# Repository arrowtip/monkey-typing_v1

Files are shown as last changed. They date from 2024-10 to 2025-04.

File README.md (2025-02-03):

# monkey_typing V1
<p align="center">
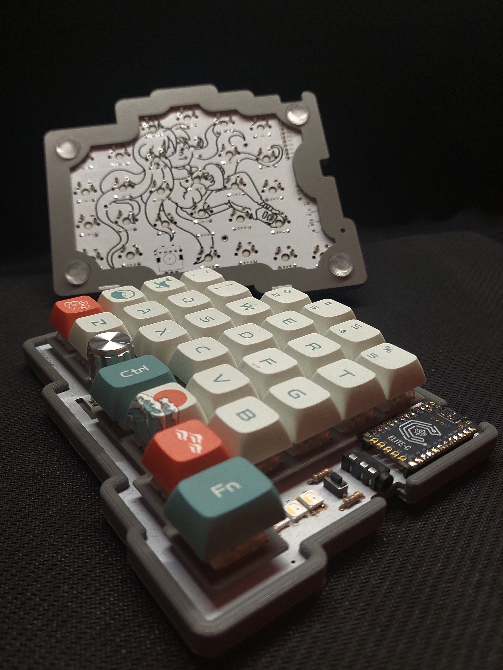
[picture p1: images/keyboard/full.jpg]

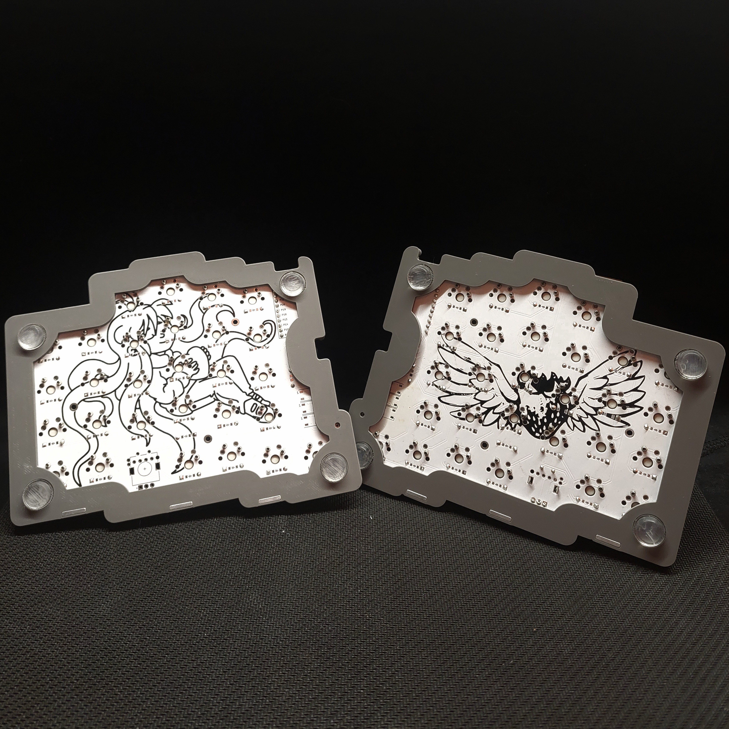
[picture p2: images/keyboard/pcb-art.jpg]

</p>

## Setup
Install ergogen cli:
```bash
$ npm i ergogen
```

## Usage
To compile the ergogen config into an (unrouted) KiCad PCB run
```bash
$ cd ergogen/
$ make
```
This will create a KiCad PCB under `ergogen/output/pcbs/monkey-typing_v1.kicad_pcb`.
Then copy this file to another location for routing.
Prerouted versions of the keyboard can be found in `kicad/`.

## Build
### Parts
- [3D-printable case](https://cad.onshape.com/documents/ed0d6a4fe642353b2203faf0/w/5ff3ead430589bfdb49bdc3b/e/f0c0ddc8bc3d8364728c5712)
- [3D-printable switch plate](https://cad.onshape.com/documents/5edfe701ad9f2b4f2a2a6781/w/f609051c12ccf6833f78234f/e/c55f49f04b746962ac1a3068)
- 58 diodes (e.g. 1N48)
- 56 mx-style switches
- mx-style keycaps
- rotary encoder (e.g. KY-040)
- 2 through-hole reset buttons
- 2 TRRS jacks TRRS-PJ-320A
- TRRS cable
- 4 6.8 kOhm resistors
- 6 WS2812B or SK6812 LEDs
- 2 microcontrollers (pro-micro or elite-c)

### Assembly
The RGB diodes are hard to hand solder, so using reflow soldering here is 
recommended.

Add two small drops of solder to the three-way jumpers below the microcontroller
on each side to connect the i2c SDA line/GND from the TRRS jack to the 
microcontroller.

Snapping the PCB into the 3D printed case might require a bit of force.
Solder all components before inserting the PCB into the case,
as removing the PCB again from the case might be difficult.

> [!CAUTION]
> Never plug the TRRS cable in or out while the keyboard is connected via USB!

### Firmware
Flash the [QMK firmware](https://github.com/arrowtip/monkey-typing_qmk) to the microcontrollers on both sides.

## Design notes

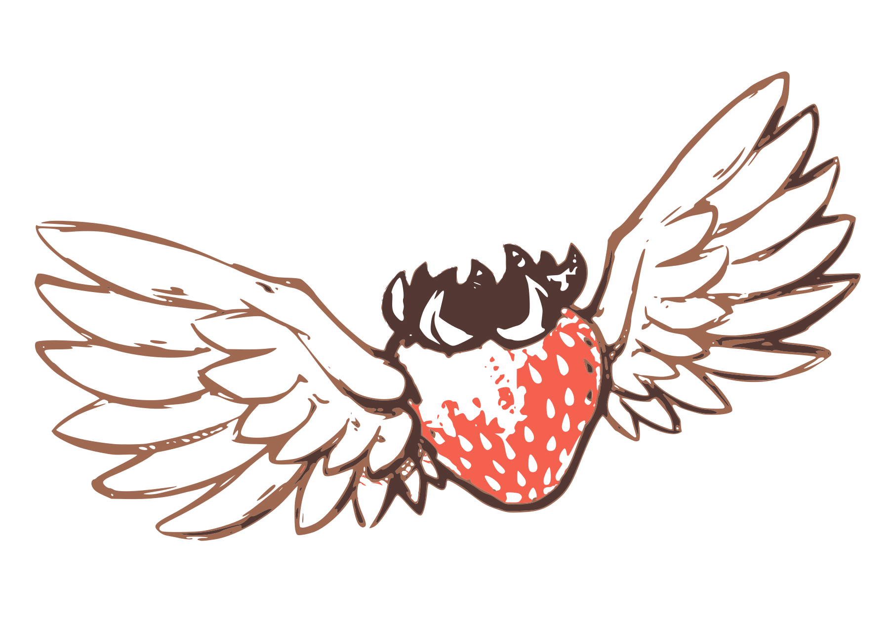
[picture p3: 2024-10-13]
images/celeste/winged-berry_reduced.png

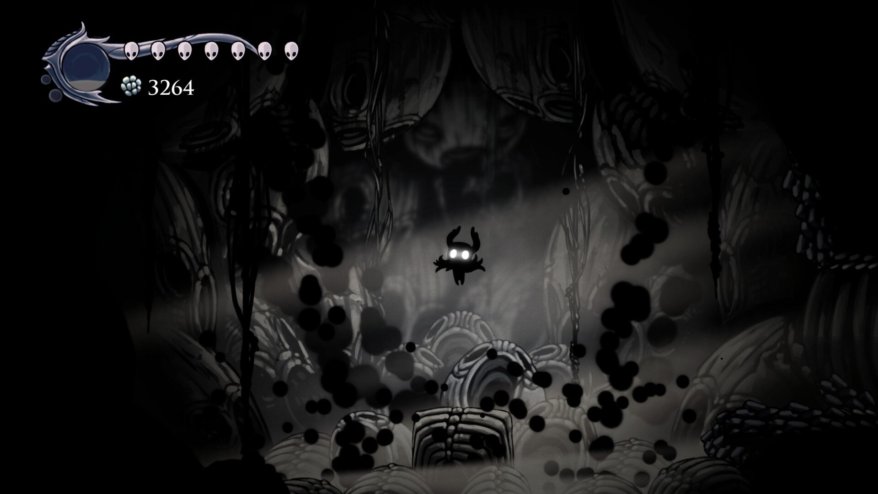
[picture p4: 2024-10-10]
images/hollow-knight/hollow-knight_shadow.jpeg

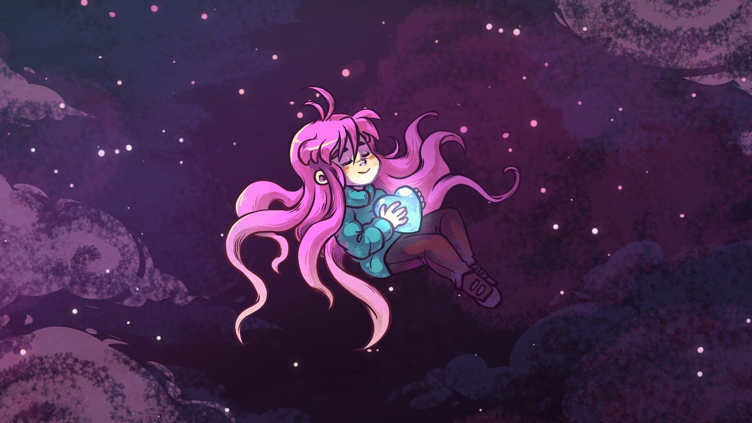
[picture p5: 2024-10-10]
images/celeste/celeste_crystal-heart_orig.jpeg

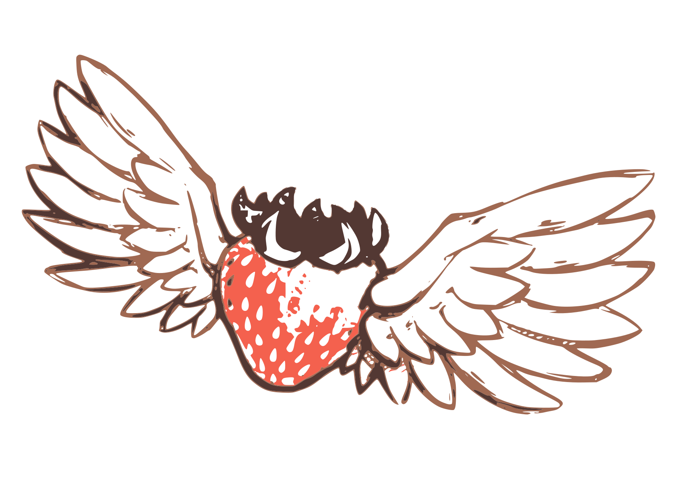
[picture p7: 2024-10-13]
images/celeste/winged-berry_reduced_mirrored.png

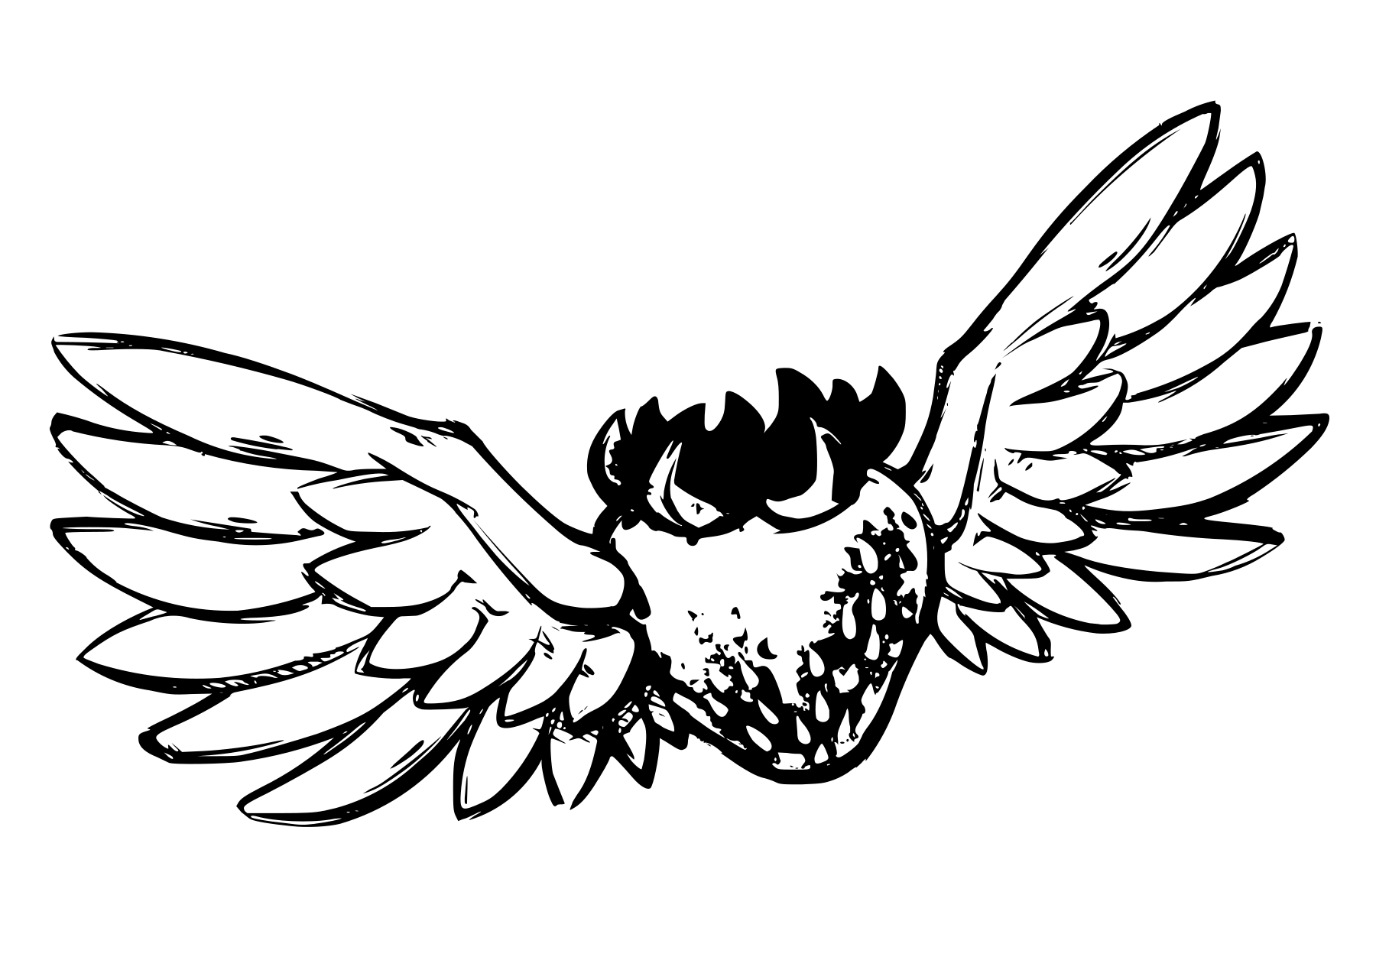
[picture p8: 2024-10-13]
images/celeste/winged-berry_01_optimized.png

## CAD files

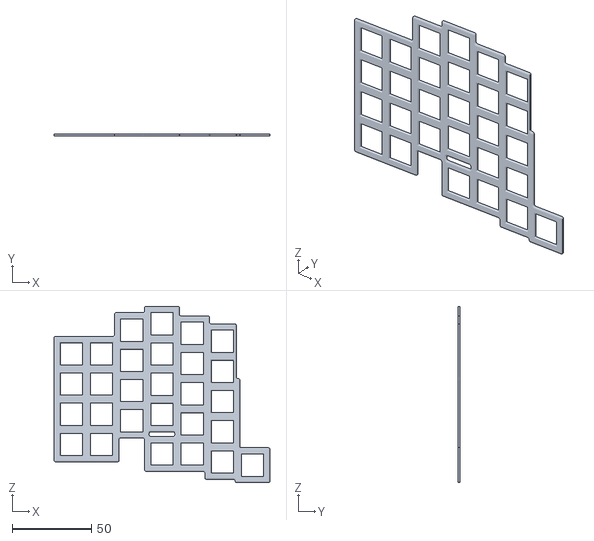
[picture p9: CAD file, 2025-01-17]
parts/switch-plate_v1.stl
136.3 x 1.50 x 111.2

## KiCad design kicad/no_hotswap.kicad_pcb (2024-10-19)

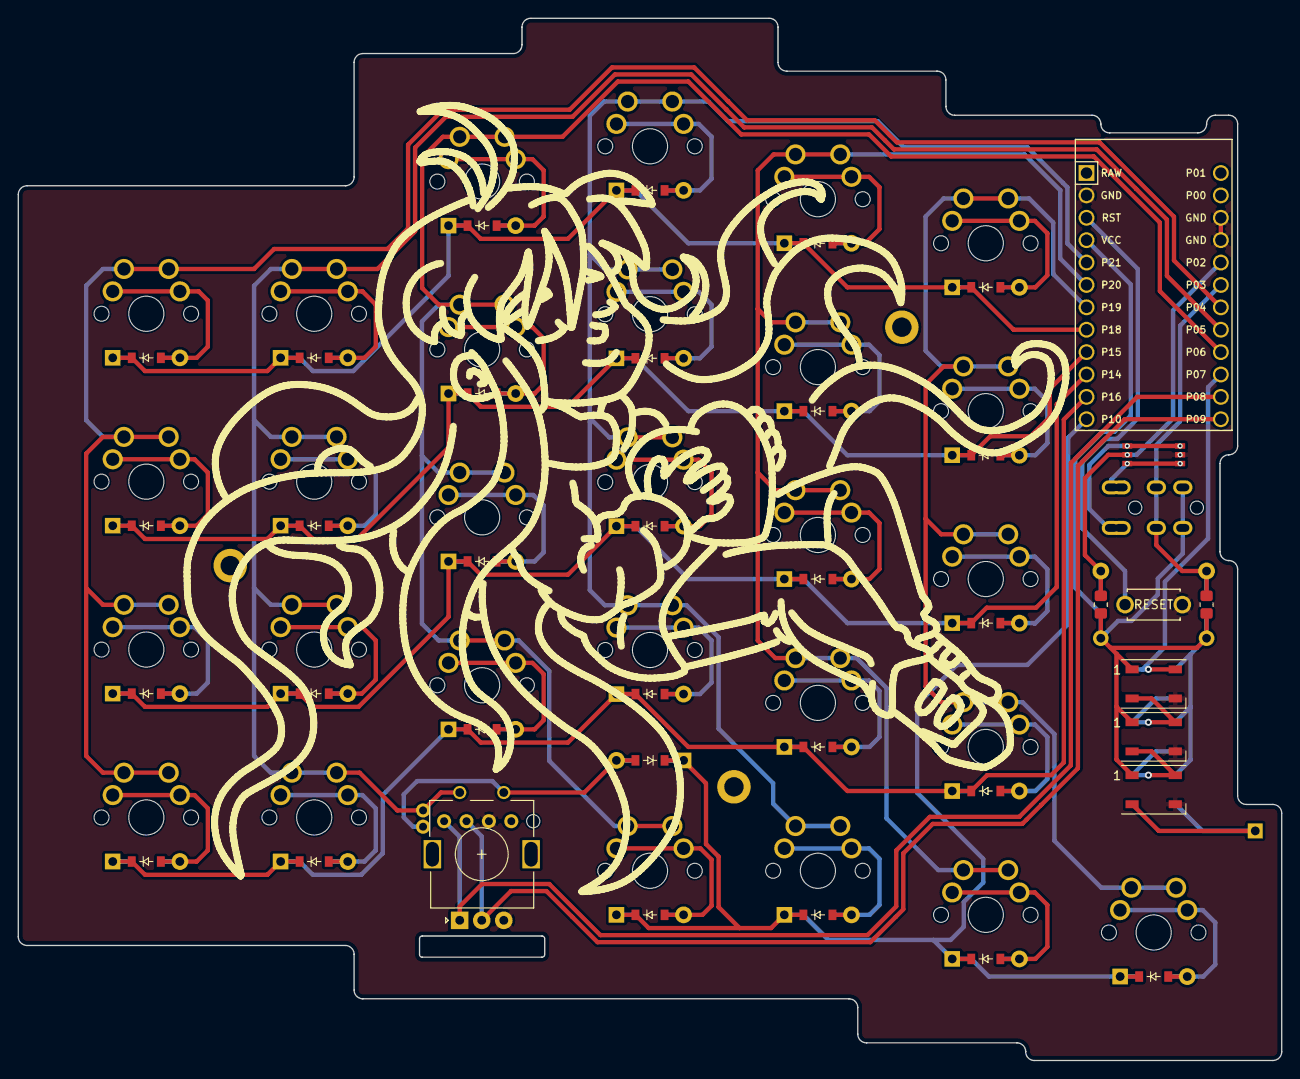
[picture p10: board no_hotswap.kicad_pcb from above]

Board: 2 copper layers, 143.3 x 118.2 mm, 68 parts (0 on the bottom side), 49 nets.

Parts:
D1, D2, D3, D4, D5, D6, D7, D8, D9, D10, D11, D12, D13, D14, D15, D16, D17, D18, D19, D20, D21, D22, D23, D24, D25, D26, D27, D28, D29: ComboDiode
Ju31, Ju32: Jumper; threeway_jumper
MCU1: ProMicro
R1, R2: ComboResistor
ROT1: rotary_encoder
S1, S2, S3, S4, S5, S6, S7, S8, S9, S10, S11, S12, S13, S14, S15, S16, S17, S18, S19, S20, S21, S22, S23, S24, S25, S26, S27, S28: MX
TRRS1: TRRS-PJ-320A-dual
_1: ResetSW
_2, _3, _4: MountingHole_2.2mm_M2

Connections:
GND: Ju32.2, Ju32.5, MCU1.2, MCU1.15, MCU1.16, ROT1.B, _1.2
P2: Ju31.2, Ju31.5, MCU1.17, R1.2
P3: MCU1.18, R2.2, TRRS1.3
P4: MCU1.19, S1.1, S2.1, S3.1, S4.1
P5: MCU1.20, ROT1.1, S5.1, S6.1, S7.1, S8.1
P6: MCU1.21, S9.1, S10.1, S11.1, S12.1, S25.1
P8: MCU1.23, ROT1.A
P9: MCU1.24, ROT1.C
P10: D25.1, D26.1, D27.1, D28.1, D29.1, MCU1.12
P14: D2.1, D6.1, D10.1, D14.1, D18.1, D22.1, MCU1.10
P15: D3.1, D7.1, D11.1, D15.1, D19.1, D23.1, MCU1.9
P16: D1.1, D5.1, D9.1, D13.1, D17.1, D21.1, MCU1.11
P18: D4.1, D8.1, D12.1, D16.1, D20.1, D24.1, MCU1.8
P19: MCU1.7, S21.1, S22.1, S23.1, S24.1, S28.1
P20: MCU1.6, S17.1, S18.1, S19.1, S20.1, S27.1
P21: MCU1.5, S13.1, S14.1, S15.1, S16.1, S26.1
RST: MCU1.3, _1.1
VCC: MCU1.4, R1.1, R2.1, TRRS1.4
far_thumb: D27.2, S27.2
farfar_thumb: D28.2, S28.2
home_thumb: D26.2, S26.2
index_bottom: D17.2, S17.2
index_home: D18.2, S18.2
index_num: D20.2, S20.2
index_top: D19.2, S19.2
inner_bottom: D21.2, S21.2
inner_home: D22.2, S22.2
inner_num: D24.2, S24.2
inner_top: D23.2, S23.2
middle_bottom: D13.2, S13.2
middle_home: D14.2, S14.2
middle_num: D16.2, S16.2
middle_top: D15.2, S15.2
my_col_row: D29.2, ROT1.2
near_thumb: D25.2, S25.2
outer_bottom: D1.2, S1.2
outer_home: D2.2, S2.2
outer_num: D4.2, S4.2
outer_top: D3.2, S3.2
pinky_bottom: D5.2, S5.2
pinky_home: D6.2, S6.2
pinky_num: D8.2, S8.2
pinky_top: D7.2, S7.2
ring_bottom: D9.2, S9.2
ring_home: D10.2, S10.2
ring_num: D12.2, S12.2
ring_top: D11.2, S11.2
trrs_gnd: Ju31.3, Ju31.6, Ju32.3, Ju32.6, TRRS1.1
trrs_sda: Ju31.1, Ju31.4, Ju32.1, Ju32.4, TRRS1.2

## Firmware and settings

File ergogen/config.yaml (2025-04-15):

meta:
  engine: 4.1.0
  author: Jakob Schmid
  version: v1.1
units:
  U: 19.05 # 19.05mm MX spacing
  u: 19 # 19mm MX spacing
  cx: 18 # 18mm Choc X spacing
  cy: 17 # 17mm Choc Y spacing
  px: U/2+5
  py: U/2+5
  switch_x: 14 # width of switch cutout
  switch_y: 14
  plate_x: 22 # width of switch plate around switches
  plate_y: 22
  stagger_ring: 15
  stagger_middle: 4
  stagger_index: -6
  stagger_inner: -5
  stagger_farfar: -2
  trrs_y_shift: -30
  reset_y_shift: -41
  trrs_jumper_y_shift: trrs_y_shift+6
points:
  key.spread: U
  key.padding: U
  zones:
    matrix_left:
      anchor:
        rotate: 0
        shift: [100, -150]
      columns:
        outer:
          key.col_net: D4
        pinky:
          key.col_net: C6
        ring:
          key:
            stagger: stagger_ring
            col_net: D7
        middle:
          key:
            stagger: stagger_middle
            col_net: F4
        index:
          key:
            stagger: stagger_index
            col_net: F5
        inner:
          key:
            stagger: stagger_inner
            col_net: F6
      rows:
        bottom:
          row_net: B2
        home:
          row_net: B3
        top:
          row_net: B1
        num:
          row_net: F7
    thumbfan:
      anchor:
        ref: matrix_left_middle_bottom
        shift: [0, stagger_index-U]
      columns:
        near:
          key.col_net: D7
        home:
          key.col_net: F4
        far:
          key:
            stagger: stagger_inner
            col_net: F5
        farfar:
          key:
            stagger: stagger_farfar
            col_net: F6
      rows:
        thumb:
          row_net: B6
outlines:
  board:
    - what: polygon
      operation: stack
      points:
        - ref: matrix_left_outer_num
          shift: [-px, py]
        - ref: matrix_left_pinky_num
          shift: [U-px, py]
        - ref: matrix_left_ring_num
          shift: [-px, py]
        - ref: matrix_left_ring_num
          shift: [U-px, py]
        - ref: matrix_left_middle_num
          shift: [-px, py]
        - ref: matrix_left_middle_num
          shift: [px, py]
        - ref: matrix_left_index_num
          shift: [px-U, py]
        - ref: matrix_left_index_num
          shift: [px, py]
        - ref: matrix_left_inner_num
          shift: [px-U, py]
          # usb-c indent
        - ref: matrix_left_inner_num
          shift: [U-6, py]
        - ref: matrix_left_inner_num
          shift: [U-6, py-2]
        - ref: matrix_left_inner_num
          shift: [U+6, py-2]
        - ref: matrix_left_inner_num
          shift: [U+6, py]

        - ref: matrix_left_inner_num
          shift: [1.5U, py]
          # trrs indent
        - ref: matrix_left_inner_num
          shift: [1.5U, trrs_y_shift+6]
        - ref: matrix_left_inner_num
          shift: [1.5U-2, trrs_y_shift+6]
        - ref: matrix_left_inner_num
          shift: [1.5U-2, trrs_y_shift-6]
        - ref: matrix_left_inner_num
          shift: [1.5U, trrs_y_shift-6]

        - ref: thumbfan_farfar_thumb
          shift: [0.5U, py]
        - ref: thumbfan_farfar_thumb
          shift: [px, py]
        - ref: thumbfan_farfar_thumb
          shift: [px, -py]
        - ref: thumbfan_farfar_thumb
          shift: [-px, -py]
        - ref: thumbfan_far_thumb
          shift: [U-px, -py]
        - ref: thumbfan_far_thumb
          shift: [-px, -py]
        - ref: thumbfan_home_thumb
          shift: [U-px, -py]
        - ref: thumbfan_near_thumb
          shift: [-px, -py]
        - ref: thumbfan_near_thumb
          shift: [-px-U, -py]
        - ref: matrix_left_pinky_bottom
          shift: [U-px, -py]
        - ref: matrix_left_outer_bottom
          shift: [-px, -py]
      # make fillets work properly for 2mm edges
      fillet: 0.999
  _switch_cutouts:
    - what: rectangle
      where: true
      size: [switch_x, switch_y]
  _switch_plate_outer:
    - what: rectangle
      where: true
      size: [plate_x, plate_y]
      fillet: 0.999
  _mcu_cutout:
    - what: rectangle
      where:
        ref: matrix_left_inner_num
        shift: [U, -6]
      size: [20.5, 35]
  switch_plate:
    part1:
      name: _switch_plate_outer
    part2:
      name: _mcu_cutout
      operation: subtract
      fillet: 0.999
    part3:
      name: _switch_cutouts
      operation: subtract
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

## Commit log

2024-09-23 add i2c connection hardware
2024-09-24 add scrollwheel and rotary encoder
2024-09-25 pretty sure ws2812 footprint is broken
    [config.yaml]
2024-10-01 fix rgb footprint
2024-10-02 fix trrs symmetric problem
    [config.yaml]
2024-10-02 add mounting holes
    [no_hotswap.kicad_pcb]
2024-10-02 change routing setup for big, beafy tracks!!
    [no_hotswap.kicad_pcb]
2024-10-12 add madeline to silkscreen
2024-10-13 add winged berry
2024-10-15 fix trrs jack
    [no_hotswap.kicad_pcb]
2024-10-19 increase hole diameter for low profile sockets
2024-10-19 start routing
    [no_hotswap.kicad_pcb]
2024-10-19 routing done. silkscreen still needs attention
    [no_hotswap.kicad_pcb]
2024-10-19 fix silkscreen
    [no_hotswap.kicad_pcb]
2024-11-04 add switch plate
    [switch-plate_v1.stl]
2025-01-16 add prerouted mx-style key switch footprint
2025-01-17 add stl for switch plate
    [switch-plate_v1.stl]
2025-01-17 add proper scale and positioning to silkscreen art
    closes #3
2025-01-19 add version number to PCB
    closes #5
2025-01-19 add silkscreen on both sides for resistors and 3-way jumper
    closes #6
    closes #7
2025-01-25 fix silkscreen of micro controller
    closes #1
    [config.yaml]
2025-03-04 move footprints into separate repository
2025-04-15 fix pre-routed key switches
    [config.yaml]
